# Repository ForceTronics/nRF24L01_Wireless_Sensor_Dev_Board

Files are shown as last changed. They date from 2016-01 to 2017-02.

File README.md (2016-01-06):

# nRF24L01_Wireless_Sensor_Dev_Board
This repository is for Arduino code that goes to an open source Wireless Sensor Development Board that is being developed on the ForceTronics YouTube channel. Please note that this code is still currently in early draft form. The Wireless Sensor Dev Board will feature an ATmega 328p MCU and a nRF24L01+ Transceiver Module. The 328p will be programmed using the Arduino IDE (Pro Mini 3.3V 8MHz bootloader). In the future this wireless sensor dev board will be available for sale at www.forcetronics.com

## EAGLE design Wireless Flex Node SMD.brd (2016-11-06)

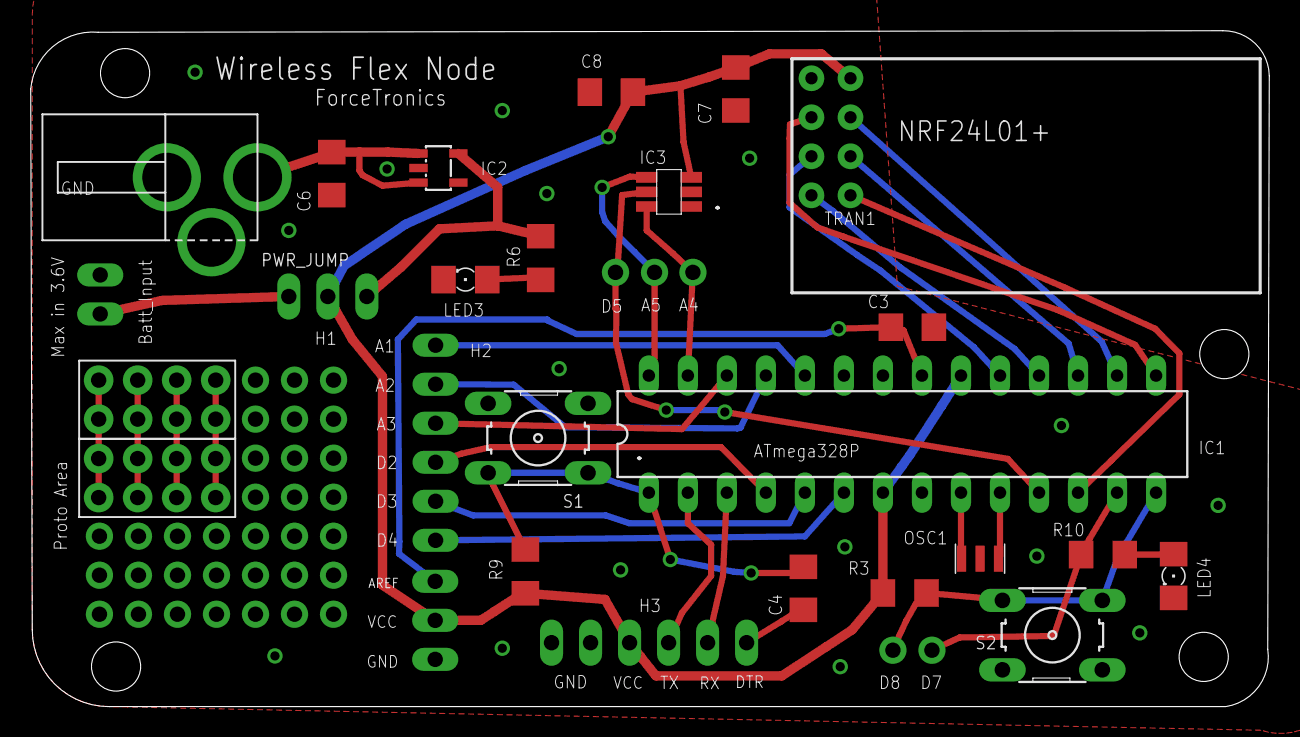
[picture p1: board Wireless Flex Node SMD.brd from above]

Board: 2 copper layers, 80.6 x 44.0 mm, 31 parts (0 on the bottom side), 35 nets.

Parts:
A4, A5: 1PINHEADER_S
BATT_INPUT: 2PINHEADER
C3, C4, C8: 0.1uF; C1206
C6, C7: 10uF; C1206
D5, D7, D8: 1PINHEADER_S
DGHDFGH: ATMEGA168-PU; DIL28-3
IC2: LP2985; SOT23
LED3, LED4: 1206
N1, N5: 6PINHEADER
N3: 2.1MM_DC_JACK
NRF24L01+: NRF24L01A; NRF24L01
OSC1: CSTCE_RESONATOR
P1, P2: 2X4_HEADER
PWR_JUMP: 3PINHEADER
R3: 100k; R1206
R6, R10: 220; R1206
R9: 10k; R1206
S1, S2: B3F-10XX
U$2: 3PINHEADER
U$8: STTS751; STTS751-SOT23-6L

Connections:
A5: D5.P$1, DGHDFGH.11, U$8.5
GND: BATT_INPUT.P0, C3.2, C6.2, C7.2, C8.2, DGHDFGH.8, DGHDFGH.22, IC2.2, LED3.C, LED4.C, N1.P4, N1.P5, N3.GND1, N3.GND2, NRF24L01+.P1, OSC1.2, S1.3, S1.4, S2.3, S2.4, U$2.N0, U$8.1, U$8.2
unnamed: DGHDFGH.10, OSC1.1
unnamed: DGHDFGH.18, NRF24L01+.P7
unnamed: DGHDFGH.19, NRF24L01+.P5
unnamed: DGHDFGH.17, NRF24L01+.P6
unnamed: DGHDFGH.16, NRF24L01+.P4
unnamed: DGHDFGH.15, NRF24L01+.P3
unnamed: D7.P$1, DGHDFGH.13, R10.2
unnamed: C4.2, N1.P0
unnamed: DGHDFGH.9, OSC1.3
unnamed: C4.1, DGHDFGH.1, R9.1, S1.1, S1.2
unnamed: D8.P$1, DGHDFGH.14, R3.1, S2.1, S2.2
unnamed: LED4.A, R10.1
unnamed: DGHDFGH.3, N1.P1
unnamed: DGHDFGH.2, N1.P2
unnamed: C3.1, DGHDFGH.21, U$2.N2
unnamed: DGHDFGH.12, NRF24L01+.P8
unnamed: DGHDFGH.6, N5.P5
unnamed: DGHDFGH.5, N5.P4
unnamed: A5.P$1, DGHDFGH.28, U$8.4
unnamed: A4.P$1, DGHDFGH.27, U$8.6
unnamed: C6.1, IC2.1, IC2.3, N3.VIN
unnamed: IC2.5, PWR_JUMP.N2, R6.2
unnamed: BATT_INPUT.P1, PWR_JUMP.N0
unnamed: LED3.A, R6.1
unnamed: DGHDFGH.4, N5.P3
unnamed: DGHDFGH.26, N5.P2
unnamed: DGHDFGH.25, N5.P1
unnamed: DGHDFGH.24, N5.P0
unnamed: P1.P1, P1.P5, P2.P1, P2.P5
unnamed: P1.P2, P1.P6, P2.P2, P2.P6
unnamed: P1.P3, P1.P7, P2.P3, P2.P7
unnamed: P1.P4, P1.P8, P2.P4, P2.P8
VCC: C7.1, C8.1, DGHDFGH.7, DGHDFGH.20, N1.P3, NRF24L01+.P2, PWR_JUMP.N1, R3.2, R9.2, U$2.N1, U$8.3

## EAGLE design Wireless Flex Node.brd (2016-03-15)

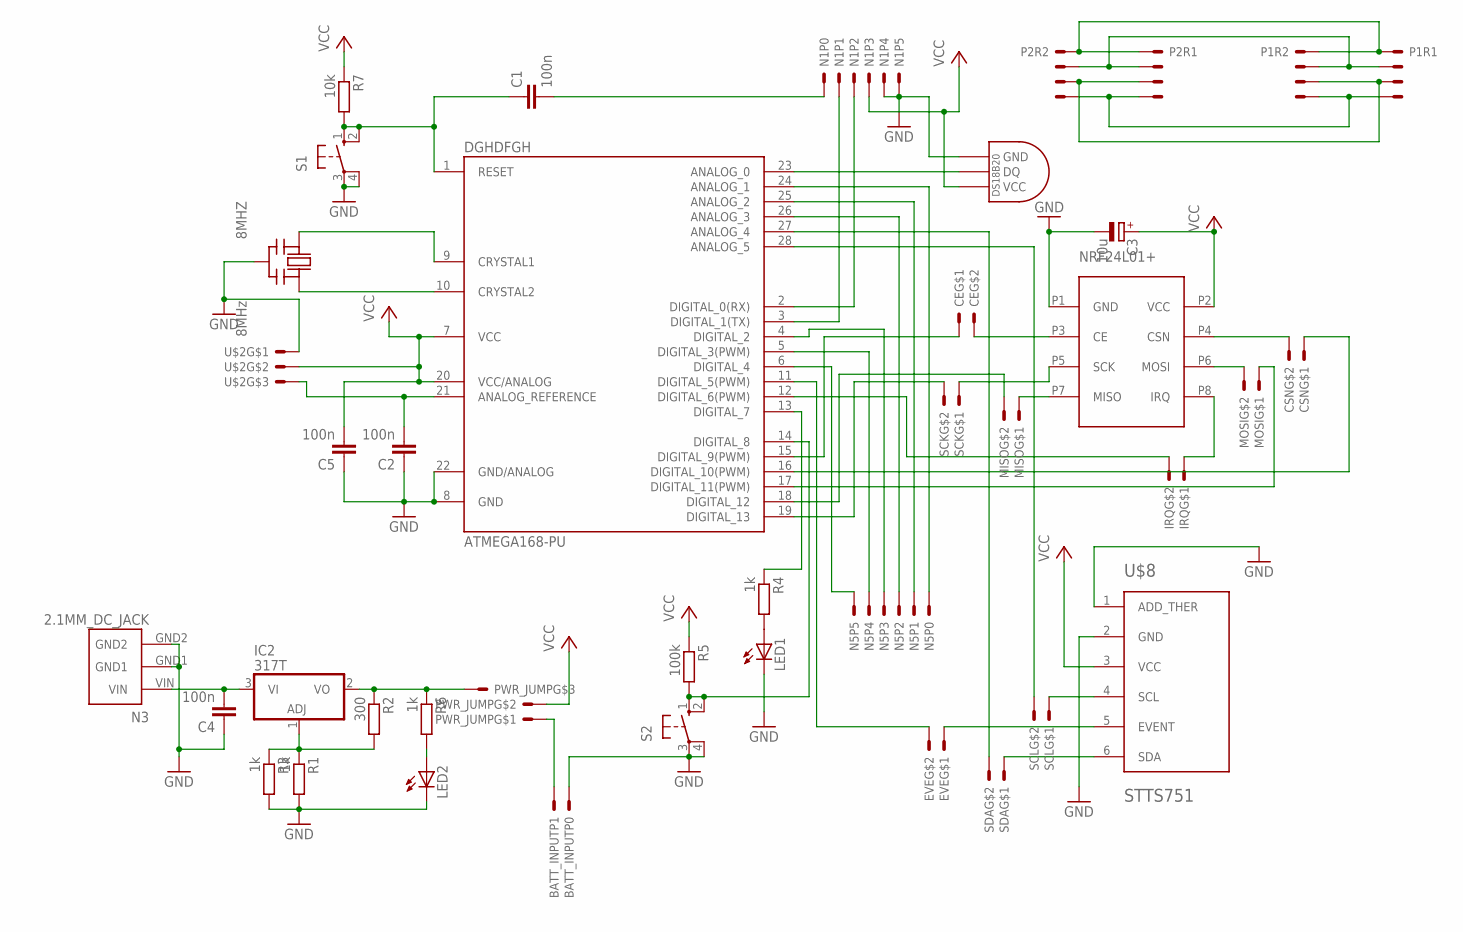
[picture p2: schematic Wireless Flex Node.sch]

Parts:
8MHZ: 8MHz; CERM_OSC
BATT_INPUT: 2PINHEADER
C1, C2, C4, C5: 100n; C050-030X075
C3: 10u; E2,5-6
CE: 2PINHEADER_S
CSN: 2PINHEADER_S
DGHDFGH: ATMEGA168-PU; DIL28-3
EVE: 2PINHEADER_S
IC2: 317T; TO220H
IRQ: 2PINHEADER_S
LED1, LED2: LED3MM
MISO: 2PINHEADER_S
MOSI: 2PINHEADER_S
N1, N5: 6PINHEADER
N3: 2.1MM_DC_JACK
NRF24L01+: NRF24L01A; NRF24L01
P1, P2: 2X4_HEADER
PWR_JUMP: 3PINHEADER
R1, R3, R4, R6: 1k; 0207/10
R2: 300; 0207/10
R5: 100k; 0207/10
R7: 10k; 0207/10
S1, S2: 10-XX; B3F-10XX
SCK: 2PINHEADER_S
SCL: 2PINHEADER_S
SDA: 2PINHEADER_S
U$2: 3PINHEADER
U$8: STTS751; STTS751-SOT23-6L
U$9: DS1820TO92; DS1820

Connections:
GND: 8MHZ.P$2 (GND), BATT_INPUT.P0, C2.1, C3.-, C4.1, C5.1, DGHDFGH.8 (GND), DGHDFGH.22 (GND/ANALOG), LED1.K (C), LED2.K (C), N1.P4, N1.P5, N3.GND1, N3.GND2, NRF24L01+.P1 (GND), R1.2, R3.2, S1.3, S1.4 (P1), S2.3, S2.4 (P1), U$2.N0, U$8.1 (ADD_THER), U$8.2 (GND), U$9.GND
unnamed: MISO.N0, NRF24L01+.P7 (MISO)
unnamed: DGHDFGH.18 (DIGITAL_12), MISO.N1
unnamed: DGHDFGH.19 (DIGITAL_13), SCK.N1
unnamed: NRF24L01+.P5 (SCK), SCK.N0
unnamed: MOSI.N1, NRF24L01+.P6 (MOSI)
unnamed: DGHDFGH.17 (DIGITAL_11(PWM)), MOSI.N0
unnamed: CE.N1, NRF24L01+.P3 (CE)
unnamed: CSN.N0, DGHDFGH.16 (DIGITAL_10(PWM))
unnamed: CSN.N1, NRF24L01+.P4 (CSN)
unnamed: CE.N0, DGHDFGH.15 (DIGITAL_9(PWM))
unnamed: DGHDFGH.13 (DIGITAL_7), R4.1
unnamed: C1.2, N1.P0
unnamed: 8MHZ.P$1 (IN), DGHDFGH.9 (CRYSTAL1)
unnamed: 8MHZ.P$3 (OUT), DGHDFGH.10 (CRYSTAL2)
unnamed: C1.1, DGHDFGH.1 (RESET), R7.2, S1.1 (S), S1.2 (S1)
unnamed: DGHDFGH.14 (DIGITAL_8), R5.2, S2.1 (S), S2.2 (S1)
unnamed: LED1.A, R4.2
unnamed: IRQ.N0, NRF24L01+.P8 (IRQ)
unnamed: DGHDFGH.3 (DIGITAL_1(TX)), N1.P1
unnamed: DGHDFGH.2 (DIGITAL_0(RX)), N1.P2
unnamed: C2.2, DGHDFGH.21 (ANALOG_REFERENCE), U$2.N2
unnamed: DGHDFGH.12 (DIGITAL_6(PWM)), IRQ.N1
unnamed: DGHDFGH.6 (DIGITAL_4), N5.P5
unnamed 26: DGHDFGH.23 (ANALOG_0), U$9.DQ; also elsewhere on the board
unnamed: DGHDFGH.5 (DIGITAL_3(PWM)), N5.P4
unnamed: SCL.N0, U$8.4 (SCL)
unnamed: DGHDFGH.28 (ANALOG_5), SCL.N1
unnamed: SDA.N0, U$8.6 (SDA)
unnamed: DGHDFGH.27 (ANALOG_4), SDA.N1
unnamed: EVE.N0, U$8.5 (EVENT)
unnamed: DGHDFGH.11 (DIGITAL_5(PWM)), EVE.N1
unnamed 34: C4.2, IC2.3 (VI), N3.VIN; also elsewhere on the board
unnamed 35: IC2.1 (ADJ), R1.1, R2.2, R3.1; also elsewhere on the board
unnamed 36: IC2.2 (VO), PWR_JUMP.N2, R2.1, R6.1; also elsewhere on the board
unnamed: BATT_INPUT.P1, PWR_JUMP.N0
unnamed: LED2.A, R6.2
unnamed: DGHDFGH.4 (DIGITAL_2), N5.P3
unnamed: DGHDFGH.26 (ANALOG_3), N5.P2
unnamed: DGHDFGH.25 (ANALOG_2), N5.P1
unnamed: DGHDFGH.24 (ANALOG_1), N5.P0
unnamed: P1.P1 (S), P1.P5 (S), P2.P1 (S), P2.P5 (S)
unnamed: P1.P2 (S1), P1.P6 (S1), P2.P2 (S1), P2.P6 (S1)
unnamed: P1.P3 (S2), P1.P7 (S2), P2.P3 (S2), P2.P7 (S2)
unnamed: P1.P4 (S3), P1.P8 (S3), P2.P4 (S3), P2.P8 (S3)
VCC: C3.+, C5.2, DGHDFGH.7 (VCC), DGHDFGH.20 (VCC/ANALOG), N1.P3, NRF24L01+.P2 (VCC), PWR_JUMP.N1, R5.1, R7.1, U$2.N1, U$8.3 (VCC), U$9.VDD (VCC); also elsewhere on the board

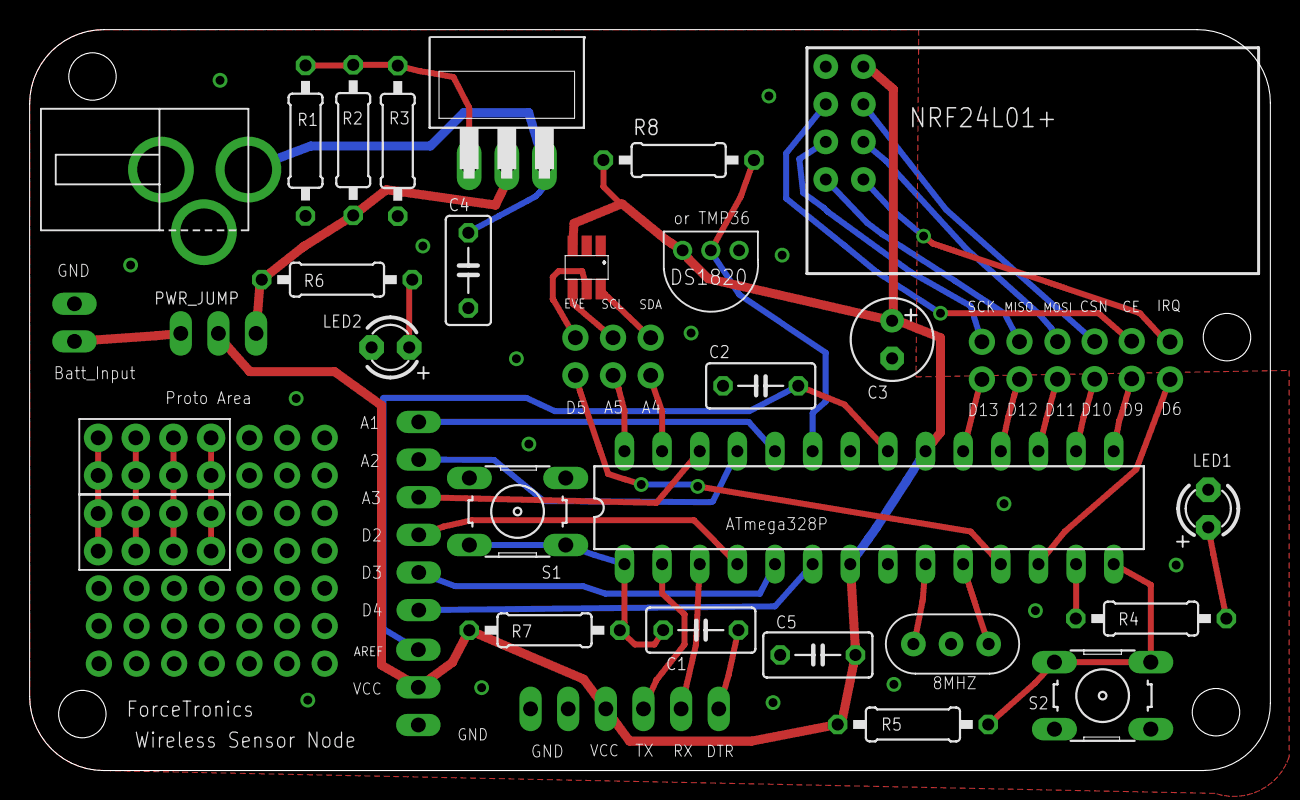
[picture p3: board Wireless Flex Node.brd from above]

Board: 2 copper layers, 83.7 x 50.0 mm, 40 parts (0 on the bottom side), 46 nets.

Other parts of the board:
IC1: 317T; TO220H
R8: 4.7k; 0207/10

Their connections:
unnamed 26: R8.2; also elsewhere on the board
unnamed 34: IC1.3; also elsewhere on the board
unnamed 35: IC1.1; also elsewhere on the board
unnamed 36: IC1.2; also elsewhere on the board
VCC: R8.1; also elsewhere on the board

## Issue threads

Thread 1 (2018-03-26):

lost communication

fermat1, 2018-03-26:
Hi I uploded the "nRF24_Network_Router_End_Device_NoLibrary" sketch into my arduino uno and the "Wireless_Sensor_Network_Coordinator.ino" sketch into another one, the problem is that the coordinator recieve data only one time and never get it again.
Is there a problem i TSR cause this recent sketch does not have one ?
am I wrong ?
I appreciate your help a lot

kny5, 2018-09-29:
It's a problem caused by the max current available in the Arduino Nano outputs. Try it again using Arduino UNO to see the difference.

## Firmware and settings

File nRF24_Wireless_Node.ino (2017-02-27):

#include "WSNode.h" //Wrapper for wireless sensor flex node design code
//#include <WSNode.h> //if you have WSNode in the Arduino library use this call
#include <RF24Network.h> //Library for networking nRF24L01s, using version https://github.com/TMRh20/RF24Network
#include <RF24.h> //Library for nRF24L01, using version https://github.com/TMRh20/RF24
#include <SPI.h> //nRF24L01 uses SPI communication
#include <EEPROM.h> //EEPROM functions
#include <Wire.h> //I2C library for STTS751 temp sensor

RF24 radio(9,10); //create object to control and communicate with nRF24L01
RF24Network network(radio); //Create object to use nRF24L01 in mesh network
WSNode wNode(network,radio); //create wireless node / sensor object

//This is an example struct for sending a payload of data with WSNode.
//Note that this is the same setup in the library, just using it as an example if you want to send a custom payload
struct payload_t
 {
    float tempSen; //temperature from onboard sensor
    bool batState; //bool to communicate battery power level, true is good and false means battery needs to be replaced
 };

void setup()
{
	SPI.begin(); //Start SPI communication
  wNode.nodeBegin(); //This must be called before network.begin
  radio.begin(); //start nRF24L01 communication and control
  //setup network communication, first argument is channel which determines frequency band module communicates on. Second argument is address of this module
  network.begin(90, wNode.thisNode); //Note that wNode.thisNode gets the node setting from EEPROM
  radio.setPALevel(RF24_PA_LOW); 
  wNode.setTempToF();//set temp measurements for Cel
}

void loop()
{
  //This function sends built-in temp data and battery state data.
  //if in end device mode this function will sleep after it transmits, after sleeping it will wake and execute any other code in the loop
  //If in router mode this function will only transmit at the user set interval. When not transmitting the loop will continue to run
  if(!wNode.sendSensorData()) {
    //If this is true transmit failed
  }
  /*This commented out code show how to send a custom payload and get temperature reading as well as battery reading*/
  //payload_t payload = {wNode.getSTTS751Temp(), wNode.checkBatteryVolt()};
  //if(!wNode.sendCustomData(&payload, sizeof(payload))) {
    //if this is true transmit failed
//  }
//if you want to run serial monitor be sure to do Serial.end() to shut it off so it does not interfer with sleep settings
 // Do not do any long delays in the loop or it will throw off the timing of the transmits, it can also cause problems with routers missing data they had to route from end device
 
}

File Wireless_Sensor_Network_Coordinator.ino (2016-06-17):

#include <RF24Network.h>
#include <RF24.h>
#include <SPI.h>

// start RF24 communication layer
RF24 radio(9,10);

// start RF24 network layer
RF24Network network(radio);

// Coordinator address
const uint16_t thisNode = 00;

// Structure of our payload coming from router and end devices
struct Payload
{
  float aDCTemp; //temperature from onboard sensor
  bool batState; //bool to communicate battery power level, true is good and false means battery needs to be replaced
};

void setup(void)
{
  Serial.begin(57600);
  Serial.println("Coordinator is online.....");
 
  SPI.begin();
  radio.begin();
  network.begin(90, thisNode);
}

void loop(void)
{
  //check network communication regularly
  network.update();

   RF24NetworkHeader header; //create header variable
   Payload payload; //create payload variable
  // Any data on the network ready to read
  while ( network.available() )
  {
    // If so, grab it and print it out
    network.read(header,&payload,sizeof(payload));
    Serial.print("The node this is from: ");
    Serial.println(header.from_node);
    Serial.print("Temperature: ");
    Serial.print(payload.aDCTemp);
    Serial.print(" Battery status: ");
    Serial.println(payload.batState);
  }
}

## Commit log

2016-01-06 Create Wireless_Sensor_Network_Coordinator.ino
    This code is just meant to serve as a simple coordinator in an RF24Network to demonstrate the router and end device code. For more information on this project go to the ForceTronics YouTube Channel h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
2016-01-21 Create Wireless Flex Node.sch
    This is the schematic file for Eagle PCB layout software
    [Wireless Flex Node.sch]
2016-01-21 Create Wireless Flex Node.brd
    Board file for Eagle PCB layout software
    [Wireless Flex Node.brd]
2016-01-21 Update nRF24_Network_Router_End_Device.ino
    Wireless sensor node Arduino code.
2016-01-21 Create ForceTronics.lbr
    This library file for the Eagle PCB software should be added to the Eagle lbr file folder when using the wireless sensor node Eagle files since parts from this library file are used in the wireless s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
2016-03-15 Create nRF24_Network_Router_End_Device_STTS751.ino
    This version of the code was made for the STTS751 Temperature sensor. Please note that this code will only work with the maniacbug R24 and RF24Network libraries on GitHub.
2016-03-15 Create nRF24_Network_Router_End_Device_DS18S20.ino
    This version of the code was made for the DS18S20 Temperature sensor, which requires that you have the DallasTemperature.h and OneWire.h libraries. Please note that this code will only work with the 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
2016-03-15 Create nRF24_Network_Router_End_Device_TMP36.ino
    This version of the code was made for the TMP36 Temperature sensor. Please note that this code will only work with the maniacbug R24 and RF24Network libraries on GitHub.
2016-03-15 Update Wireless Flex Node.brd
    [Wireless Flex Node.brd]
2016-03-15 Update Wireless Flex Node.sch
    [Wireless Flex Node.sch]
2016-06-17 Create WSNode.cpp
    One of two library files for the Wireless Flex Node software wrapper
    [WSNode.cpp]
2016-06-17 Create WSNode.h
    One of two library files for Arduino based wireless flex node board
    [WSNode.h]
2016-06-17 Create nRF24_Wireless_Node.ino
    Arduino sketch for wireless flex node board found at forcetronics.com. The sketch uses WSNode library files found here also.
    [nRF24_Wireless_Node.ino]
2016-06-17 Update Wireless_Sensor_Network_Coordinator.ino
    This Arduino sketch is meant to provide example Coordinator code for the wireless flex node design.
    [Wireless_Sensor_Network_Coordinator.ino]
2016-06-17 nRF24_Wireless_Node description
    This Arduino sketch is for the Wireless Flex Node board by ForceTronics.com. It creates a router or end device for a network of nRF24L01 transceivers using the RF24Network library TMRh20 version which is also available on GitHub. Note that this sketch uses the WSNode library that is also found here.
    [nRF24_Wireless_Node.ino]
2016-06-17 nRF24_Network_Router_End_Device_NoLib
    This Arduino sketch is for the Wireless Flex Node board by ForceTronics.com. It creates a router or end device for a network of nRF24L01 transceivers using the RF24Network library TMRh20 version which is also available on GitHub.
2016-06-18 Description Wireless Flex Node SMD.sch
    Schematic file for Eagle PCB software of Wireless Flex Node design
    [Wireless Flex Node SMD.sch]
2016-06-18 Description Wireless Flex Node SMD.brd
    Eagle board file for the forcetronics Wireless Flex Node design.
    [Wireless Flex Node SMD.brd]
2016-11-06 Update Wireless Flex Node SMD.brd
    [Wireless Flex Node SMD.brd]
2016-11-06 Update Wireless Flex Node SMD.sch
    [Wireless Flex Node SMD.sch]
